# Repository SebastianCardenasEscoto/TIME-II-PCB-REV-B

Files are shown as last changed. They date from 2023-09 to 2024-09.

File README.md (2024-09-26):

# TIME-II-PCB-REV-B
Second Revision of PCB for TIME II project of Space Technologies at Cal. The third and newest (as of 2024) revision is on branch radical. The first and oldest revision can be found [here](https://oshwlab.com/jbildy_1656/stac-time2).

## Features
- :computer: ESP32 Microcontroller
- :hotsprings: Five Plugs for Plate Heating System (Thermistors and Heaters)
- :gear: Three DRV8837 H-Bridge Motor Controllers
- :electric_plug: OR Gate PMIC for switching between USB and Battery Power
- :battery: On Flight AA Battery charging
- :floppy_disk: SD Card for Data Logging

## Differences between Previous Revision

1. Battery Support 
- Previous board had no way to switch between battery and rocket power, but battery power is required due to large wait time before launch when bacteria need to be heated.
- Current OR gate PMIC prioritizes rocket power when available and will switch to battery power when necessary.
- Since battery power is also required after the flight, this board attempts to implement on flight charging.

2. Servo and Motor Support
- To accommodate changes in mechanical design, this board supports both 3 pin servo and Brushed DC Motors.
- 3 pin servo's have largely been used for TIME II mechanical design, but the strict 500 gram weight limit might require plain DC motors.

3. The Arduino Microcontroller was replaced with an ESP32 to simplify the PCB design and bringup process.

## Pictures

### Schematic
schematic 

### Layout
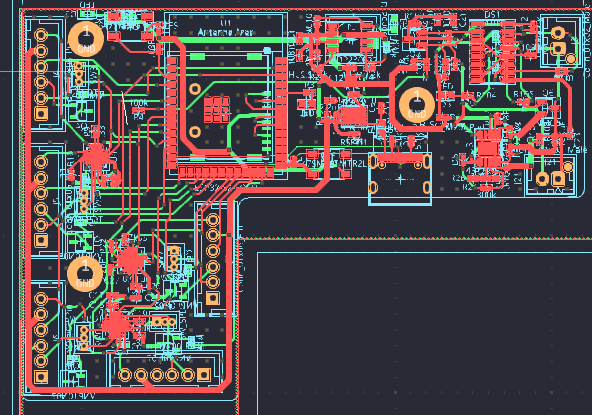
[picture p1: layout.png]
layout


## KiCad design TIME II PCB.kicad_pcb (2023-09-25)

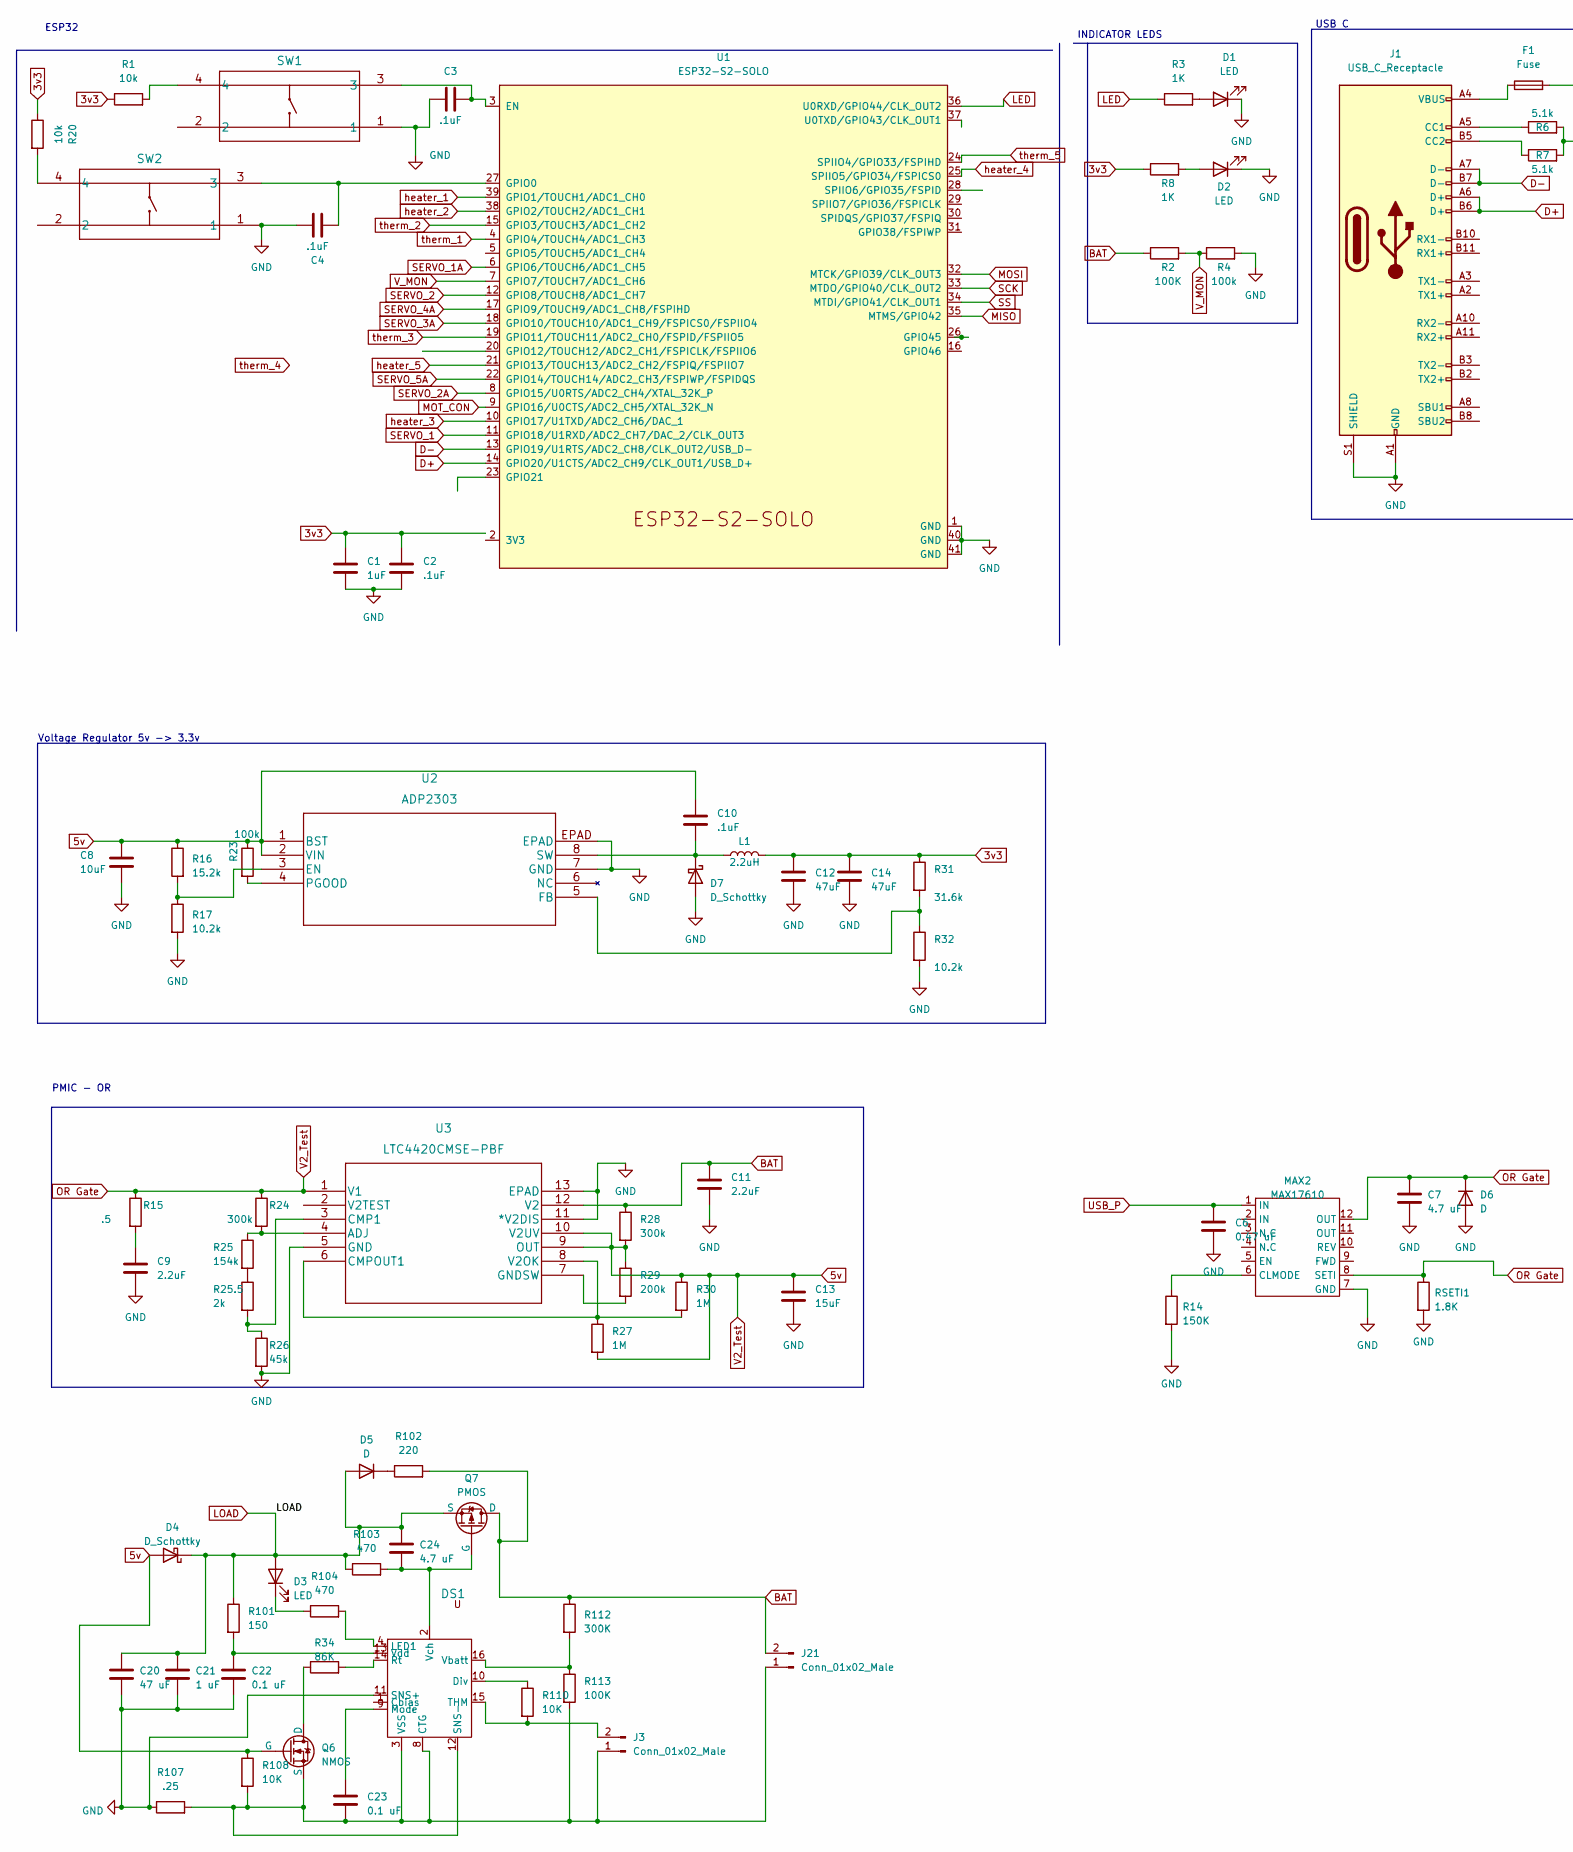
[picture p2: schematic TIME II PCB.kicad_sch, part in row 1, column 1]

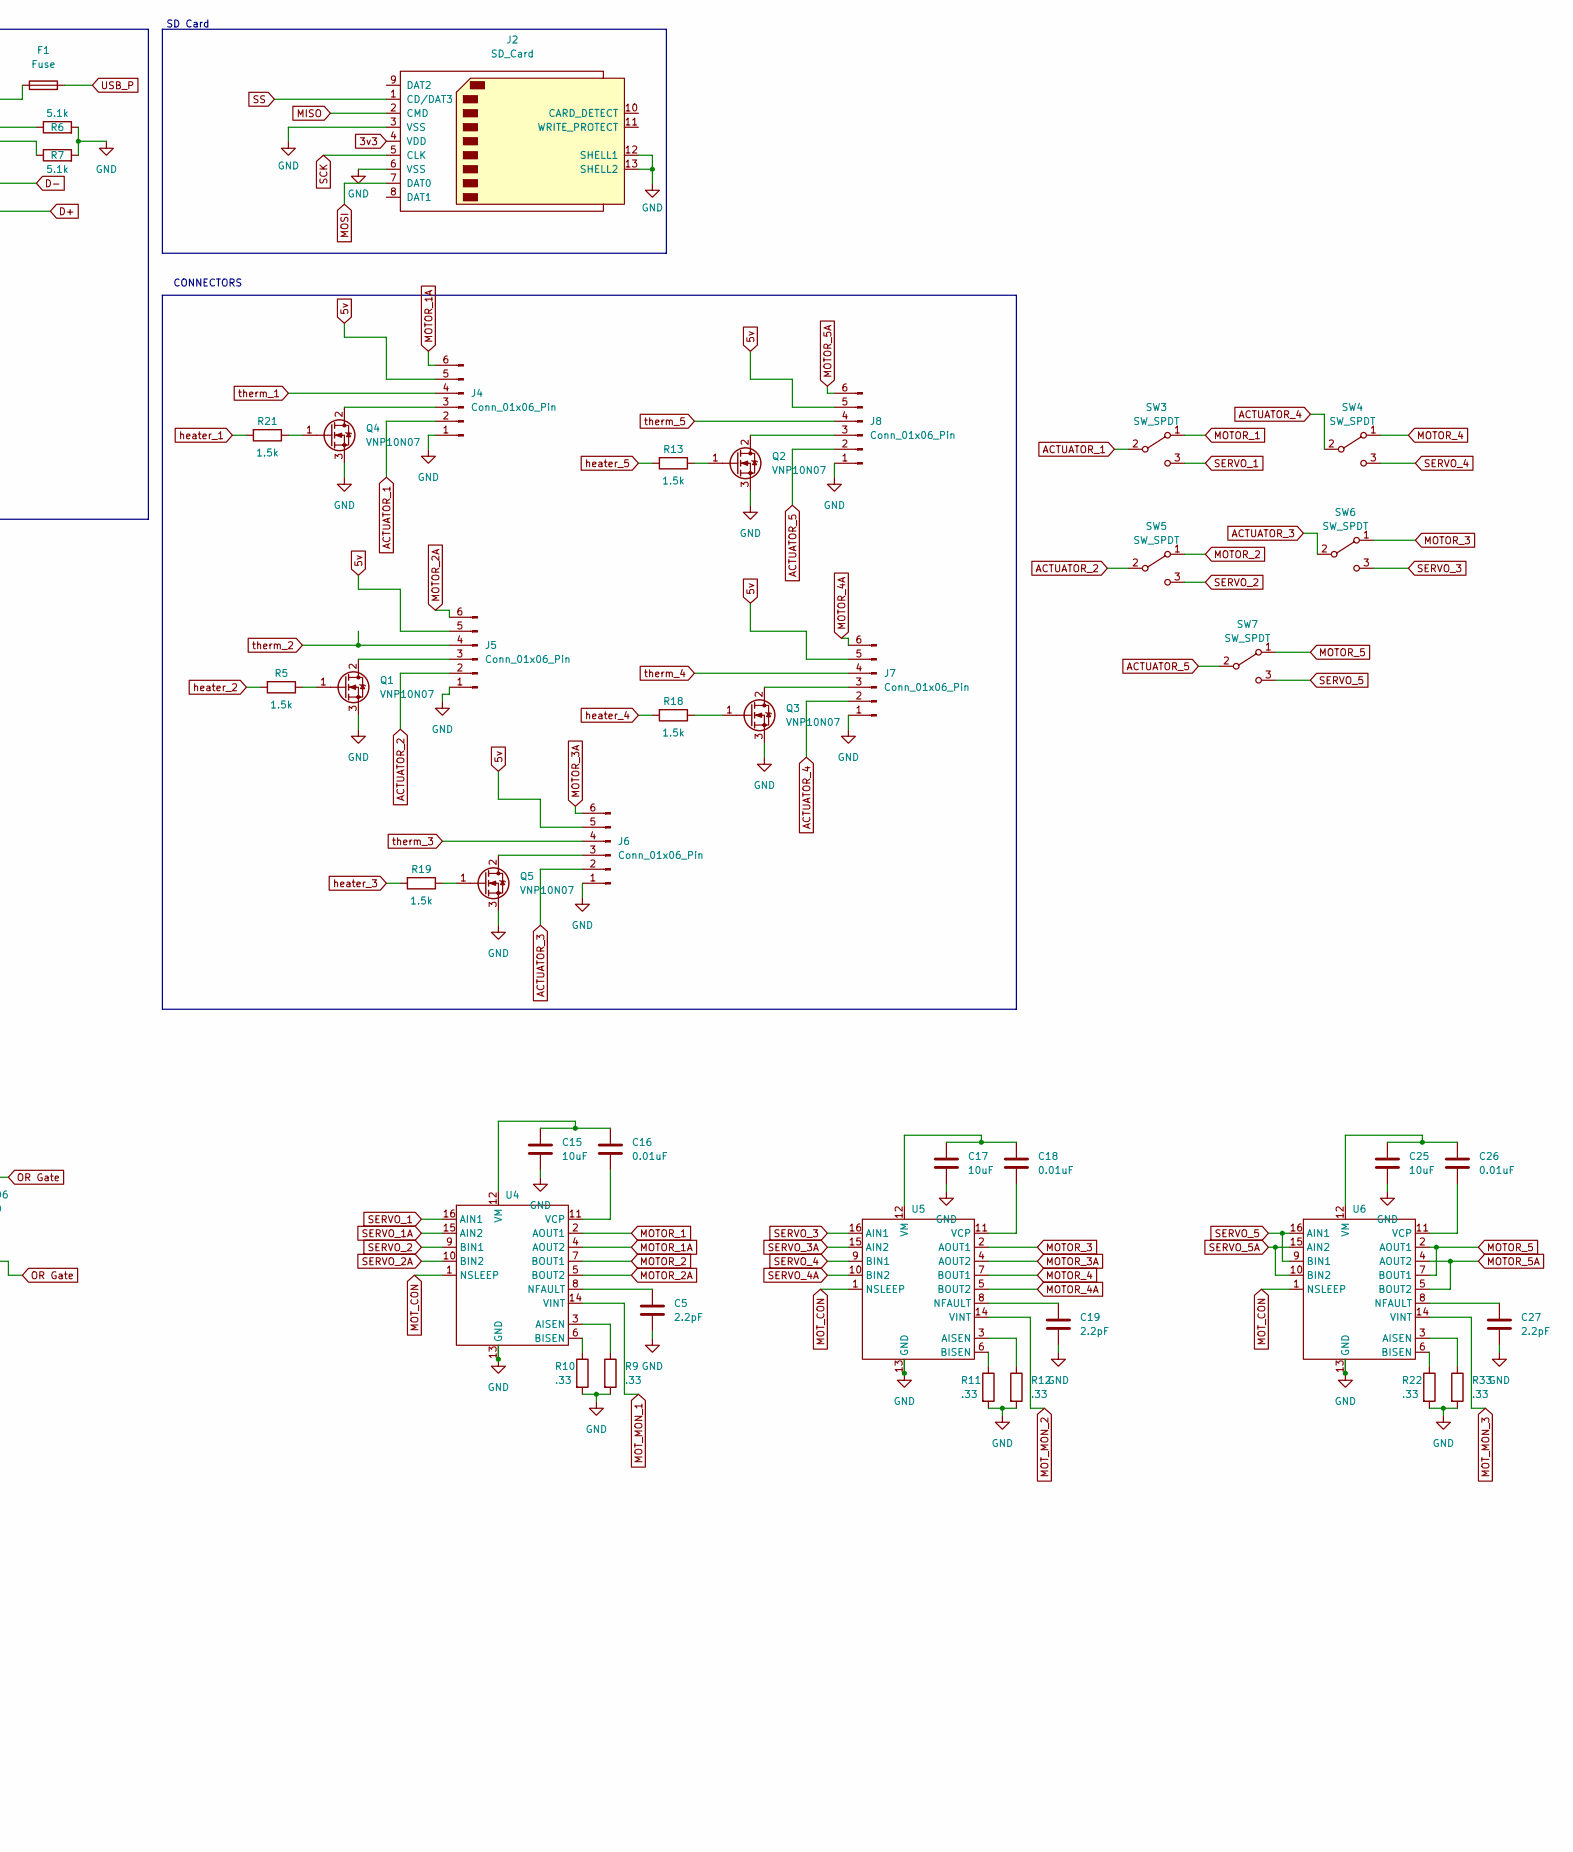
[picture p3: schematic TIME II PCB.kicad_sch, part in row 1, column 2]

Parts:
C1: 1uF; C_0402_1005Metric
C2, C3, C4, C10: .1uF; C_0402_1005Metric
C5, C19, C27: 2.2pF; C_0402_1005Metric
C6: 0.47 uF; C_0402_1005Metric
C7, C24: 4.7 uF; C_0402_1005Metric
C8, C15, C17, C25: 10uF; C_0402_1005Metric
C9, C11: 2.2uF; C_0402_1005Metric
C12, C14: 47uF; C_0402_1005Metric
C13: 15uF; C_0402_1005Metric
C16, C18, C26: 0.01uF; C_0402_1005Metric
C20: 47 uF; C_0402_1005Metric
C21: 1 uF; C_0402_1005Metric
C22, C23: 0.1 uF; C_0402_1005Metric
D1, D2, D3: LED; LED_0603_1608Metric
D4: D_Schottky; D_0402_1005Metric
D5, D6: D; D_0402_1005Metric
D7: D_Schottky; D_0603_1608Metric_Pad1.05x0.95mm_HandSolder
DS1: SOIC-16_3.9x9.9mm_P1.27mm
DS2715: (no value)
F1: Fuse; Fuse_0603_1608Metric
J1: USB_C_Receptacle; USB4105-GF-A
J2: SD_Card; MEM2075-00-140-01-A_GCT
J3, J21: Conn_01x02_Male; JST_XH_B2B-XH-AM_1x02_P2.50mm_Vertical
J4, J5, J6, J7, J8: Conn_01x06_Pin; JST_XH_B06B-XH-A_06x2.50mm_Straight
L1: 2.2uH; IND_B1047AS-2R2N=P3
MAX2: MAX17610; WDFN-12-1EP_3x3mm_P0.45mm_EP1.7x2.5mm
Q1, Q2, Q3, Q4, Q5: VNP10N07; SOT-23-3
Q6: NMOS; SOT-23-3
Q7: PMOS; SOT-23-3
R1, R20: 10k; R_0402_1005Metric
R2, R113: 100K; R_0402_1005Metric
R3, R8: 1K; R_0402_1005Metric
R4, R23: 100k; R_0402_1005Metric
R5, R13, R18, R19, R21: 1.5k; R_0402_1005Metric
R6, R7: 5.1k; R_0402_1005Metric
R9, R10, R11, R12, R22, R33: .33; R_0402_1005Metric
R14: 150K; R_0402_1005Metric
R15: .5; R_0402_1005Metric
R16: 15.2k; R_0402_1005Metric
R17, R32: 10.2k; R_0402_1005Metric
R24, R28: 300k; R_0402_1005Metric
R25: 154k; R_0402_1005Metric
R25.5: 2k; R_0402_1005Metric
R26: 45k; R_0402_1005Metric
R27, R30: 1M; R_0402_1005Metric
R29: 200k; R_0402_1005Metric
R31: 31.6k; R_0402_1005Metric
R34: 86K; R_0402_1005Metric
R101: 150; R_0402_1005Metric
R102: 220; R_0402_1005Metric
R103, R104: 470; R_0402_1005Metric
R107: .25; R_0402_1005Metric
R108, R110: 10K; R_0402_1005Metric
R112: 300K; R_0402_1005Metric
RSETI1: 1.8K; R_0402_1005Metric
SW1, SW2: PTS647SM38SMTR2LFS; SW_PTS647SM38SMTR2LFS_CNK
SW3, SW4, SW5, SW6, SW7: SW_SPDT; PinHeader_1x03_P1.27mm_Vertical
U1: ESP32-S2-SOLO
U2: ADP2303; SOIC-8-N7_3.9x4.9mm_P1.27mm
U3: LTC4420CMSE-PBF; MSOP-12-1EP_3x4mm_P0.65mm_EP1.65x2.85mm
U4, U5, U6: QFN-16-1EP_3x3mm_P0.5mm_EP1.7x1.7mm

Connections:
3v3: C1.1, C2.1, C12.1, C14.1, J2.4 (VDD), L1.2, R1.1, R8.1, R20.1, R31.1
5v: C7.1, C8.1, C10.1, C13.1, D4.2 (A), D6.1 (K), J4.5, J5.5, J6.5, J7.5, J8.5, MAX2.8 (SETI), MAX2.12 (OUT), Q6.2 (G), R15.1, R16.1, R23.1, R24.1, R27.2, R28.2, R29.1, R30.1, R108.1, RSETI1.1, U2.1 (BST), U2.2 (VIN), U3.1 (V1), U3.9 (OUT), U3.10 (V2UV)
ACTUATOR_1: J4.2, SW3.2 (B)
ACTUATOR_2: J5.2, SW5.2 (B)
ACTUATOR_3: J6.2, SW6.2 (B)
ACTUATOR_4: J7.2, SW4.2 (B)
ACTUATOR_5: J8.2, SW7.2 (B)
BAT: C11.1, J21.2, Q7.1 (D), R2.1, R28.1, R102.2, R112.1, U3.12 (V2)
D+: J1.A6 (D+), J1.B6 (D+), U1.14 (GPIO20/U1CTS/ADC2_CH9/CLK_OUT1/USB_D+)
D-: J1.A7 (D-), J1.B7 (D-), U1.13 (GPIO19/U1RTS/ADC2_CH8/CLK_OUT2/USB_D-)
GND: C1.2, C2.2, C3.1, C4.1, C5.2, C6.2, C7.2, C8.2, C9.2, C11.2, C12.2, C13.2, C14.2, C15.2, C17.2, C19.2, C20.2, C21.2, C22.2, C25.2, C27.2, D1.1 (K), D2.1 (K), D6.2 (A), D7.2 (A), DS1.11 (SNS+), J1.A1 (GND), J1.A12 (GND), J1.B1 (GND), J1.B12 (GND), J1.S1 (SHIELD), J2.3 (VSS), J2.6 (VSS), J2.12 (SHELL1), J2.13 (SHELL2), J4.1, J5.1, J6.1, J7.1, J8.1, MAX2.7 (GND), Q1.3 (S), Q2.3 (S), Q3.3 (S), Q4.3 (S), Q5.3 (S), R4.2, R6.2, R7.2, R9.2, R10.2, R11.2, R12.2, R14.2, R17.2, R22.2, R26.2, R32.2, R33.2, R107.1, RSETI1.2, SW1.1, SW2.1, U1.1 (GND), U1.40 (GND), U1.41 (GND), U2.7 (GND), U2.EPAD, U3.5 (GND), U3.11 (*V2DIS), U3.13 (EPAD), U4.13 (GND), U5.13 (GND), U6.13 (GND)
LED: R3.1, U1.36 (U0RXD/GPIO44/CLK_OUT2)
LOAD: C20.1, C21.1, C24.1, D3.2 (A), D4.1 (K), D5.2 (A), Q7.3 (S), R101.1, R103.1
MISO: J2.2 (CMD), U1.35 (MTMS/GPIO42)
MOSI: J2.7 (DAT0), U1.32 (MTCK/GPIO39/CLK_OUT3)
MOTOR_1: SW3.1 (A), U4.2 (AOUT1)
MOTOR_1A: J4.6, U4.4 (AOUT2)
MOTOR_2: SW5.1 (A), U4.7 (BOUT1)
MOTOR_2A: J5.6, U4.5 (BOUT2)
MOTOR_3: SW6.1 (A), U5.2 (AOUT1)
MOTOR_3A: J6.6, U5.4 (AOUT2)
MOTOR_4: SW4.1 (A), U5.7 (BOUT1)
MOTOR_4A: J7.6, U5.5 (BOUT2)
MOTOR_5: SW7.1 (A), U6.2 (AOUT1), U6.7 (BOUT1)
MOTOR_5A: J8.6, U6.4 (AOUT2), U6.5 (BOUT2)
MOT_CON: U1.9 (GPIO16/U0CTS/ADC2_CH5/XTAL_32K_N), U4.1 (NSLEEP), U5.1 (NSLEEP), U6.1 (NSLEEP)
MOT_MON_1: U4.14 (VINT)
MOT_MON_2: U5.14 (VINT)
MOT_MON_3: U6.14 (VINT)
unnamed: C9.1, R15.2
unnamed: D1.2 (A), R3.2
unnamed: D2.2 (A), R8.2
unnamed: D3.1 (K), R104.1
unnamed: D5.1 (K), R102.1
unnamed: C10.2, D7.1 (K), L1.1, U2.8 (SW)
unnamed: C23.2, DS1.3 (VSS), DS1.8 (CTG), DS1.12 (SNS-), J3.1, J21.1, Q6.3 (S), R107.2, R108.2, R113.2
unnamed: DS1.10 (Div), R110.1
unnamed: DS1.4 (LED1), R104.2
unnamed: C23.1, DS1.9 (Mode)
unnamed: DS1.14 (Rt), R34.2
unnamed: DS1.15 (THM), J3.2, R110.2
unnamed: DS1.16 (Vbatt), R112.2, R113.1
unnamed: C24.2, DS1.2 (Vch), Q7.2 (G), R103.2
unnamed 43: C22.1, DS1.13 (Vdd), R101.2; also elsewhere on the board
unnamed: F1.1, J1.A4 (VBUS), J1.A9 (VBUS), J1.B4 (VBUS), J1.B9 (VBUS)
unnamed: J1.A5 (CC1), R6.1
unnamed: J1.B5 (CC2), R7.1
unnamed: J4.3, Q4.2 (D)
unnamed: J5.3, Q1.2 (D)
unnamed: J6.3, Q5.2 (D)
unnamed: J7.3, Q3.2 (D)
unnamed: J8.3, Q2.2 (D)
unnamed: MAX2.6 (CLMODE), R14.1
unnamed: Q1.1 (G), R5.1
unnamed: Q2.1 (G), R13.1
unnamed: Q3.1 (G), R18.1
unnamed: Q4.1 (G), R21.1
unnamed: Q5.1 (G), R19.1
unnamed 58: Q6.1 (D), R34.1; also elsewhere on the board
unnamed: R1.2, SW1.4
unnamed: R20.2, SW2.4
unnamed: R25.2, R25.5.1
unnamed: C3.2, SW1.3, U1.3 (EN)
unnamed: C4.2, SW2.3, U1.27 (GPIO0)
unnamed: R16.2, R17.1, U2.3 (EN)
unnamed: R31.2, R32.1, U2.5 (FB)
unnamed: R23.2, U2.4 (PGOOD)
unnamed: R24.2, R25.1, U3.4 (ADJ)
unnamed: R25.5.2, R26.1, U3.3 (CMP1)
unnamed: R27.1, R30.2, U3.6 (CMPOUT1), U3.8 (V2OK)
unnamed: R29.2, U3.7 (GNDSW)
unnamed: R9.1, U4.3 (AISEN)
unnamed: R10.1, U4.6 (BISEN)
unnamed: C5.1, U4.8 (NFAULT)
unnamed: C16.2, U4.11 (VCP)
unnamed: C15.1, C16.1, U4.12 (VM)
unnamed: R12.1, U5.3 (AISEN)
unnamed: R11.1, U5.6 (BISEN)
unnamed: C19.1, U5.8 (NFAULT)
unnamed: C18.2, U5.11 (VCP)
unnamed: C17.1, C18.1, U5.12 (VM)
unnamed: R33.1, U6.3 (AISEN)
unnamed: R22.1, U6.6 (BISEN)
unnamed: C27.1, U6.8 (NFAULT)
unnamed: C26.2, U6.11 (VCP)
unnamed: C25.1, C26.1, U6.12 (VM)
SCK: J2.5 (CLK), U1.33 (MTDO/GPIO40/CLK_OUT2)
SERVO_1: SW3.3 (C), U1.11 (GPIO18/U1RXD/ADC2_CH7/DAC_2/CLK_OUT3), U4.16 (AIN1)
SERVO_1A: U1.6 (GPIO6/TOUCH6/ADC1_CH5), U4.15 (AIN2)
SERVO_2: SW5.3 (C), U1.12 (GPIO8/TOUCH8/ADC1_CH7), U4.9 (BIN1)
SERVO_2A: U1.8 (GPIO15/U0RTS/ADC2_CH4/XTAL_32K_P), U4.10 (BIN2)
SERVO_3: SW6.3 (C), U5.16 (AIN1)
SERVO_3A: U1.18 (GPIO10/TOUCH10/ADC1_CH9/FSPICS0/FSPIIO4), U5.15 (AIN2)
SERVO_4: SW4.3 (C), U5.9 (BIN1)
SERVO_4A: U1.17 (GPIO9/TOUCH9/ADC1_CH8/FSPIHD), U5.10 (BIN2)
SERVO_5: SW7.3 (C), U6.9 (BIN1), U6.16 (AIN1)
SERVO_5A: U1.22 (GPIO14/TOUCH14/ADC2_CH3/FSPIWP/FSPIDQS), U6.10 (BIN2), U6.15 (AIN2)
SS: J2.1 (CD/DAT3), U1.34 (MTDI/GPIO41/CLK_OUT1)
USB_P: C6.1, F1.2, MAX2.1 (IN)
V_MON: R2.2, R4.1, U1.7 (GPIO7/TOUCH7/ADC1_CH6)
heater_1: R21.2, U1.39 (GPIO1/TOUCH1/ADC1_CH0)
heater_2: R5.2, U1.38 (GPIO2/TOUCH2/ADC1_CH1)
heater_3: R19.2, U1.10 (GPIO17/U1TXD/ADC2_CH6/DAC_1)
heater_4: R18.2, U1.25 (SPIIO5/GPIO34/FSPICS0)
heater_5: R13.2, U1.21 (GPIO13/TOUCH13/ADC2_CH2/FSPIQ/FSPIIO7)
therm_1: J4.4, U1.4 (GPIO4/TOUCH4/ADC1_CH3)
therm_2: J5.4, U1.15 (GPIO3/TOUCH3/ADC1_CH2)
therm_3: J6.4, U1.19 (GPIO11/TOUCH11/ADC2_CH0/FSPID/FSPIIO5)
therm_4: J7.4
therm_5: J8.4, U1.24 (SPIIO4/GPIO33/FSPIHD)

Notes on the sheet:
INDICATOR LEDS
Voltage Regulator 5v -> 3.3v
ESP32
SD Card
PMIC - OR
USB C
CONNECTORS

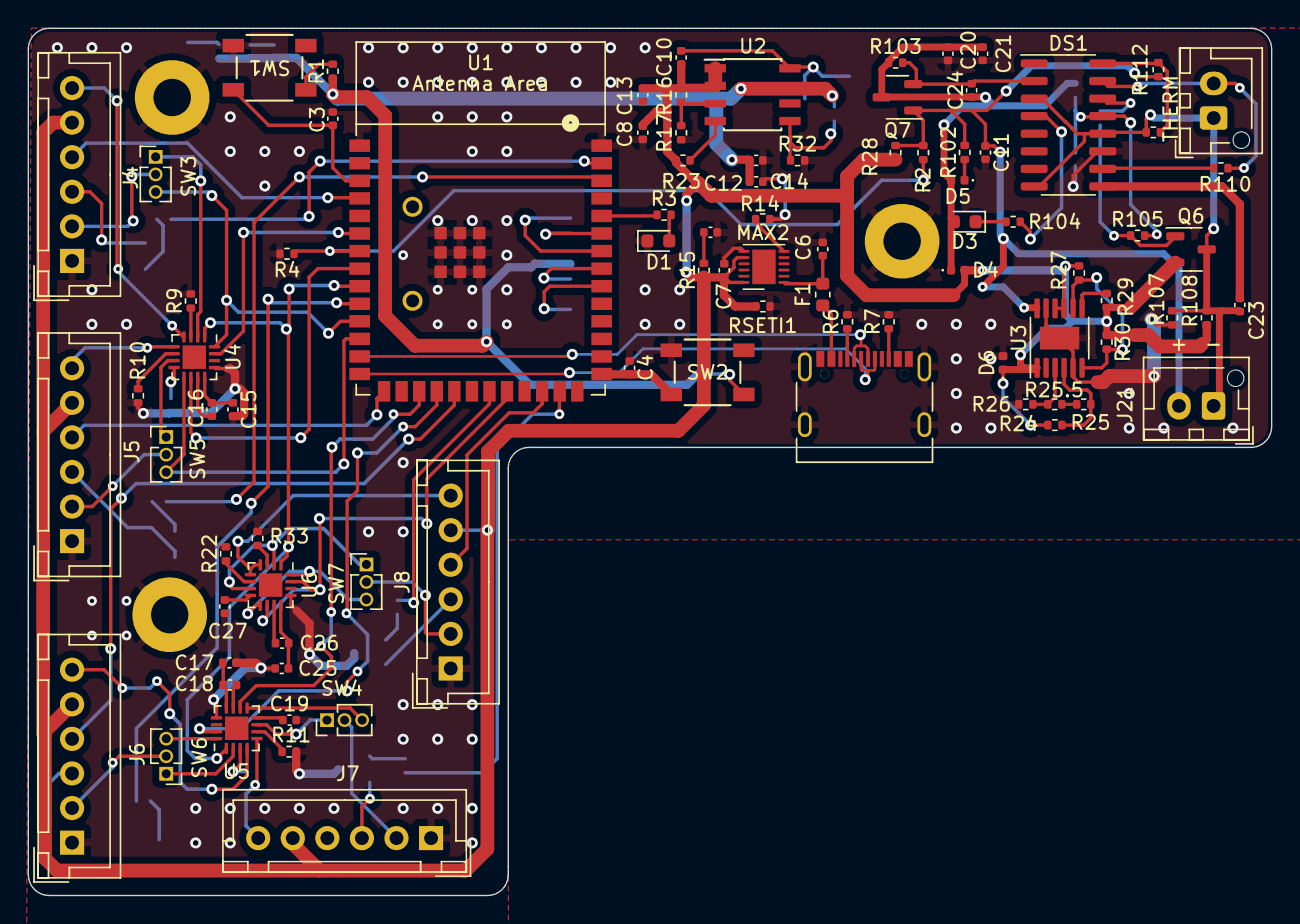
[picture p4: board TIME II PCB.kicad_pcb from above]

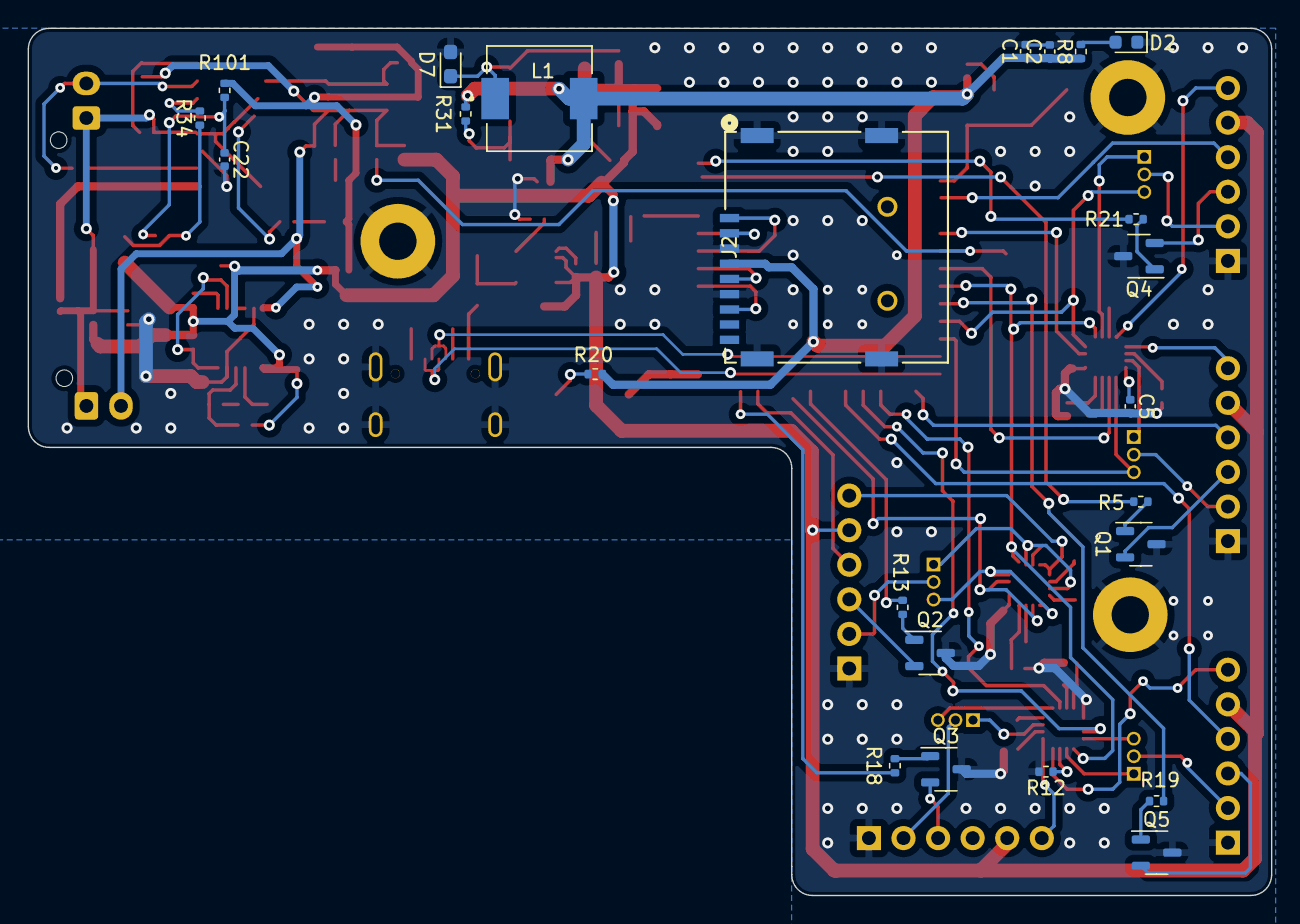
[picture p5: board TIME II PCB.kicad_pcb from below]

Board: 2 copper layers, 89.9 x 62.7 mm, 113 parts (24 on the bottom side), 106 nets.

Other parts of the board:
R105: R; R_0402_1005Metric

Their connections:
unnamed 43: R105.2; also elsewhere on the board
unnamed 58: R105.1; also elsewhere on the board

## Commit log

2023-04-25 Project Parts
    [ESP32-S2-SOLO-U-N4R2.step]
2023-09-21 motor driver
    [TIME II PCB.kicad_pcb, TIME II PCB.kicad_sch]
2024-02-24 main (old rev) local changes push
    [TIME II PCB.kicad_sch]

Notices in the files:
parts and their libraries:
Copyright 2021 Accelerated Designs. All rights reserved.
